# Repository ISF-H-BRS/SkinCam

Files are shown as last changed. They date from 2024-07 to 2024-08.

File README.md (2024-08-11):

# ISF SkinCam

## Introduction

The objective of the SkinCam project was to implement a camera system for real-time skin detection and face verification using multispectral short-wavelength infrared (SWIR) imaging. It originated from previous research projects carried out at Bonn-Rhein-Sieg University of Applied Sciences, such as [FeGeb](https://www.h-brs.de/de/fegeb) and [Beyond SPAI](https://www.h-brs.de/en/beyond-spai).

<p align="center">
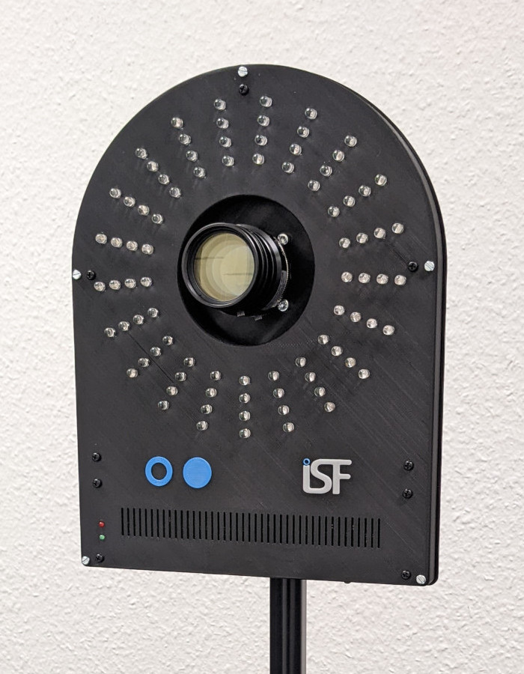
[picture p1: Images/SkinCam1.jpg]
  
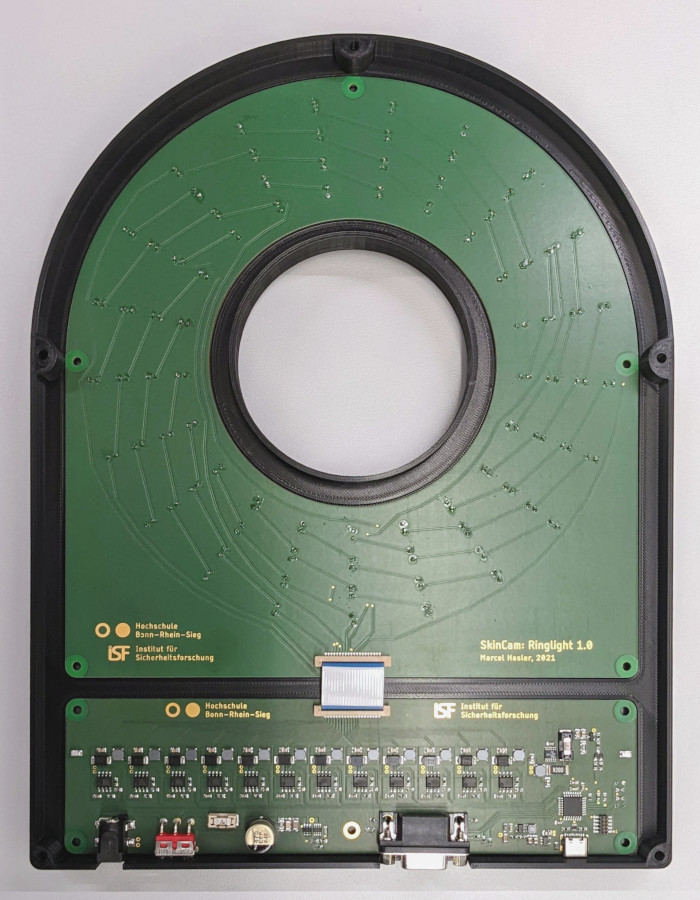
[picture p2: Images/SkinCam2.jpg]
  
</p>

Based on the original concepts and designs, a new and improved system was developed, offering higher frame rates and optimized SWIR lighting. It is currently being used in various successor projects in biometrics research, such as [BIOLAB](https://www.h-brs.de/en/isf/biolab).

<p align="center">
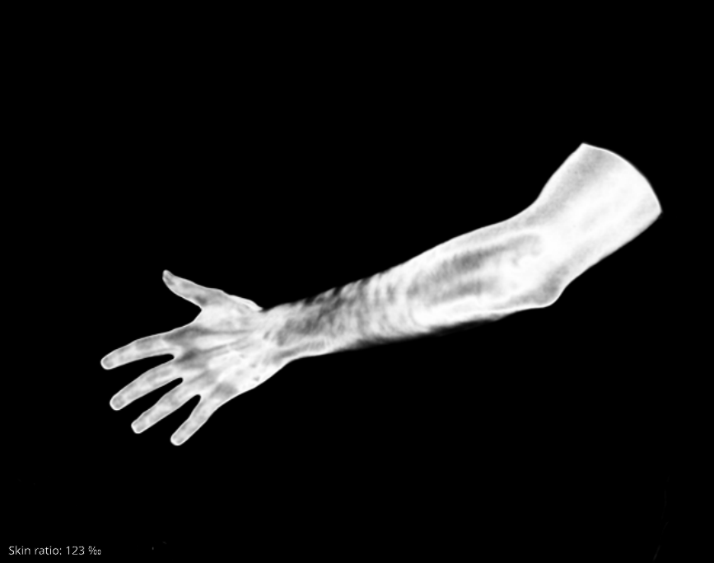
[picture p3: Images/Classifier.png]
  
</p>

## Concept

The system is based on a Goldeye G-033 SWIR camera by Allied Vision, combined with a multispectral ring light operating at wavelengths of 1050, 1300 and 1550 nm. By evaluating the absorption ratios at these specific wavelengths, it is possible to identify those pixels which have properties characteristic of human skin using a pre-trained classifier.

<p align="center">
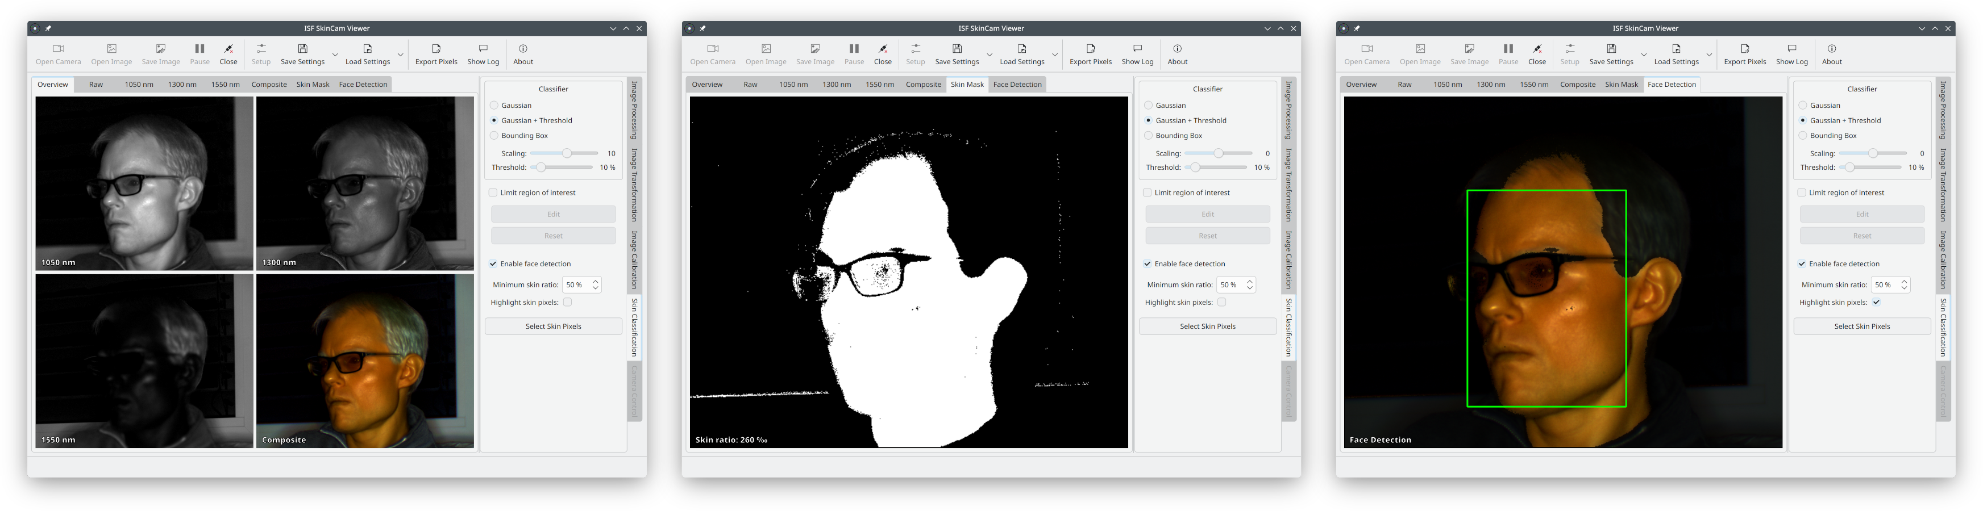
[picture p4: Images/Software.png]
  
</p>

## Software

The software developed as part of this project is based on code originally written for the project Beyond SPAI, which itself was based on the FeGeb project but extended the original concept by using three SWIR cameras simultaneously, using relay optics to split the image.

A number of image processing filters were implemented to compensate for imperfections in the relay optics. While these aren't strictly necessary for a single-camera system, they were retained in the SkinCam software anyway.

The implementation uses OpenCL for real-time image processing and skin classification and employs a number of other optimizations in order to achieve a stable frame rate of 40 Hz even on mid- to low-end systems.

In addition to the OpenCL [development headers](https://github.com/KhronosGroup/OpenCL-CLHPP), [Qt6](https://www.qt.io/product/qt6), [FreeImage](https://freeimage.sourceforge.io/), [libIFD](https://github.com/ISF-H-BRS/FaceDetector), [libusb](https://libusb.info/), [libzip](https://libzip.org/) and the [Vimba SDK](https://www.alliedvision.com/en/products/vimba-sdk/) are required to build and run the software. Since the Vimba terms and conditions do not permit end-users to download or use the software, the SkinCam software is by default compiled without support for the Vimba SDK.

The firmware directory contains project files for both the newly developed system, which is based on a STM32 microcontroller, as well as for the original FeGeb system, which was based on an 8-bit AVR microcontroller.

A number of captured test images are provided within the repository that can be used to evaluate the software without having the actual camera system available. A setup file is also provided, containing suitable settings as well as necessary calibration and classification data.

## License

All source code for the software and firmware is licensed under the terms of the GNU General Public License (GPLv3). All schematics, layout and CAD files are licensed under the terms of the Creative Commons Attribution-ShareAlike International Public License (CC BY-SA). See COPYING in the respective subdirectories for details.

## Further Information

This document will be expanded over time to further detail some of the underlying concepts. For the time being, detailed information on the original project and concepts can be found in Holger Steiner's PhD thesis, available online [here](http://www.grk1564.uni-siegen.de/publicationPDFbyID?ID=825).

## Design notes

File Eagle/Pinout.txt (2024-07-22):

+--------------+--------+--------+-------+
| Signal       | Hirose | Wire   | D-SUB |
+==============+========+========+=======+
| External GND |      1 | Black  |     1 |
+--------------+--------+--------+-------+
| External 12V |      2 | Red    |     5 |
+--------------+--------+--------+-------+
| Trigger TTL  |      4 | Yellow |     7 |
+--------------+--------+--------+-------+
| Feedback TTL |      6 | Blue   |     8 |
+--------------+--------+--------+-------+
| Isolated GND |      7 | Green  |     2 |
+--------------+--------+--------+-------+
| Isolated PWR |     10 | White  |     6 |
+--------------+--------+--------+-------+
| Trigger ISO  |     11 | Purple |     3 |
+--------------+--------+--------+-------+
| Feedback ISO |     12 | Orange |     4 |
+--------------+--------+--------+-------+

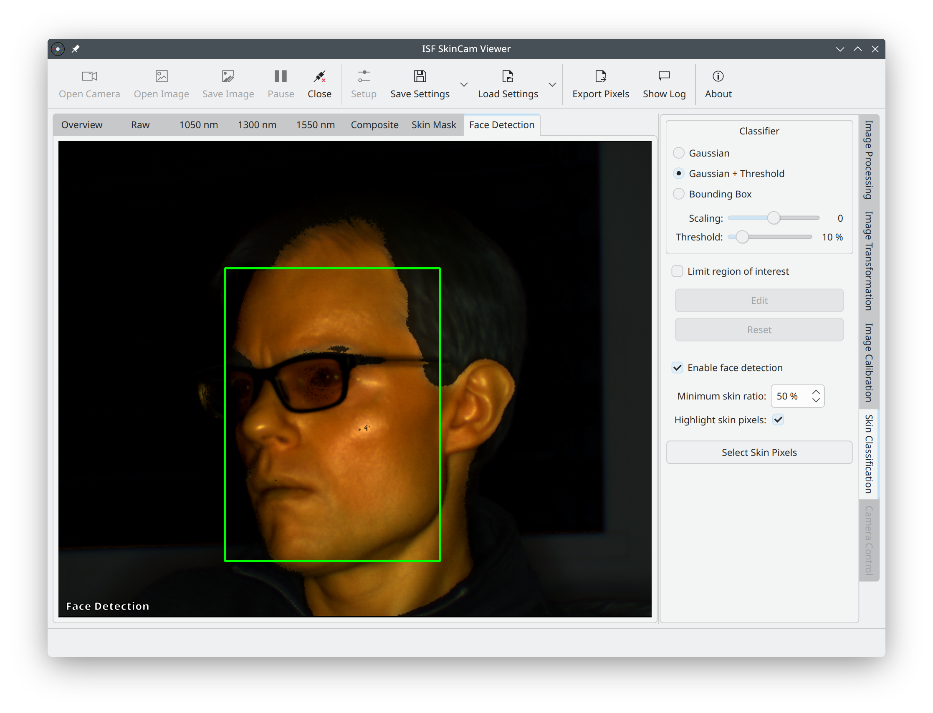
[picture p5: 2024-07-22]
Images/Software3.png

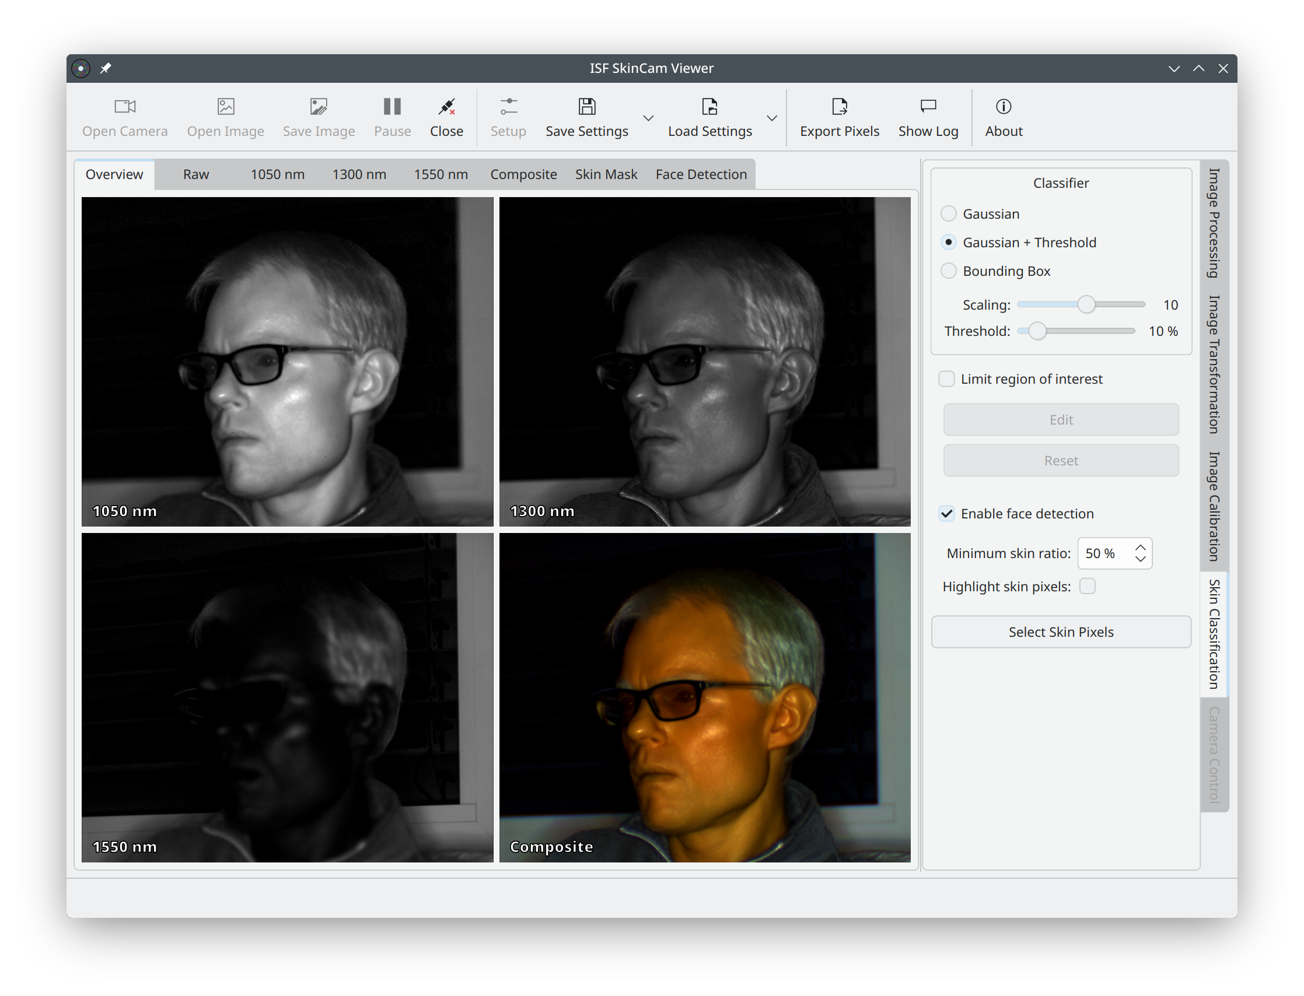
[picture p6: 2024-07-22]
Images/Software1.png

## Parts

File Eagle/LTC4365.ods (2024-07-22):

V_os | 0,003
I_uv | 1E-08
UV_th | 11
OV_th | 13
R1+R2 | 300000
R3 | 6300000
R3 selected | 6340000
R1 | 255384,615384615
R1 selected | 255000
R2 | 45000
R2 selected | 47000
UV_th actual | 10,9966887417219
OV_th actual | 13,0235294117647

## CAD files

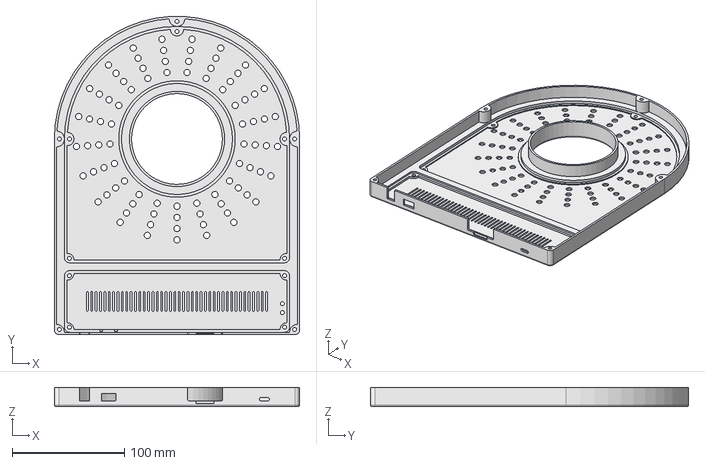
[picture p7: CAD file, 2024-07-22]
FreeCAD/HousingTop.FCStd
219.0 x 283.8 x 17.1 mm

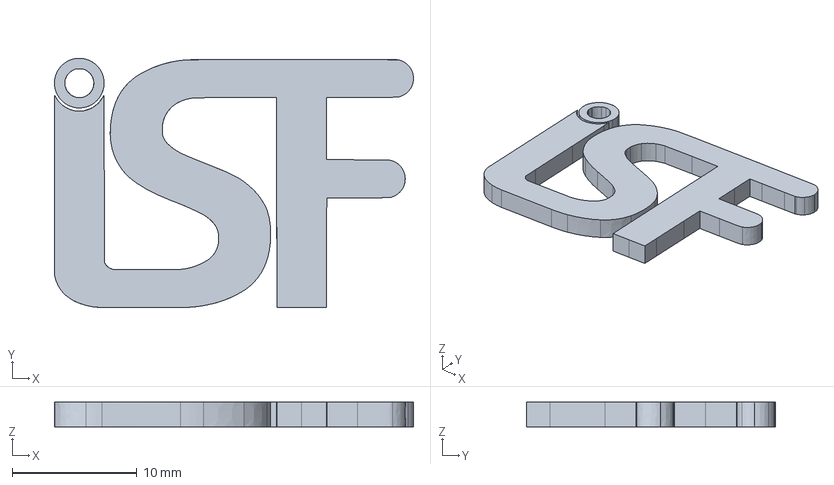
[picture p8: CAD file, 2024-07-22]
FreeCAD/ISF.FCStd
28.8 x 20.0 x 2.00 mm

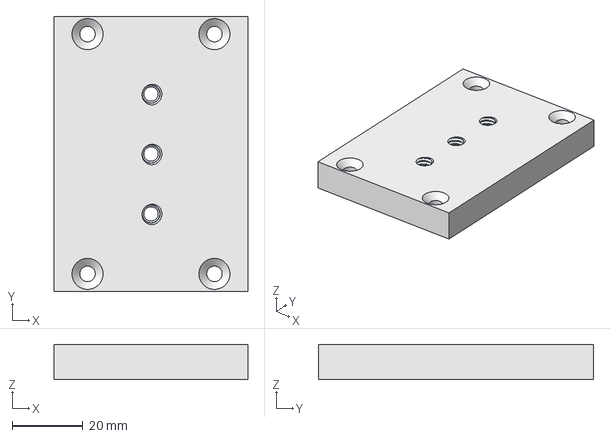
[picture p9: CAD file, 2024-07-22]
FreeCAD/Adapter.FCStd
55.0 x 78.0 x 10.0 mm

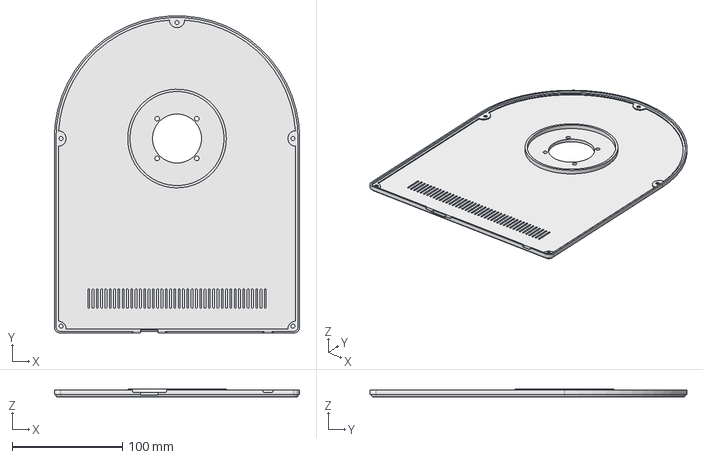
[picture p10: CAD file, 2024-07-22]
FreeCAD/HousingBottom.FCStd
222.4 x 287.2 x 7.00 mm

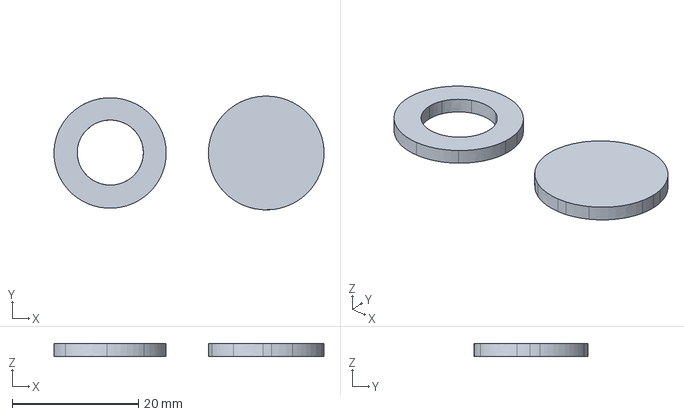
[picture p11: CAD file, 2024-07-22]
FreeCAD/H-BRS.FCStd
42.7 x 18.0 x 2.00 mm

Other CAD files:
FreeCAD/SharedData.FCStd

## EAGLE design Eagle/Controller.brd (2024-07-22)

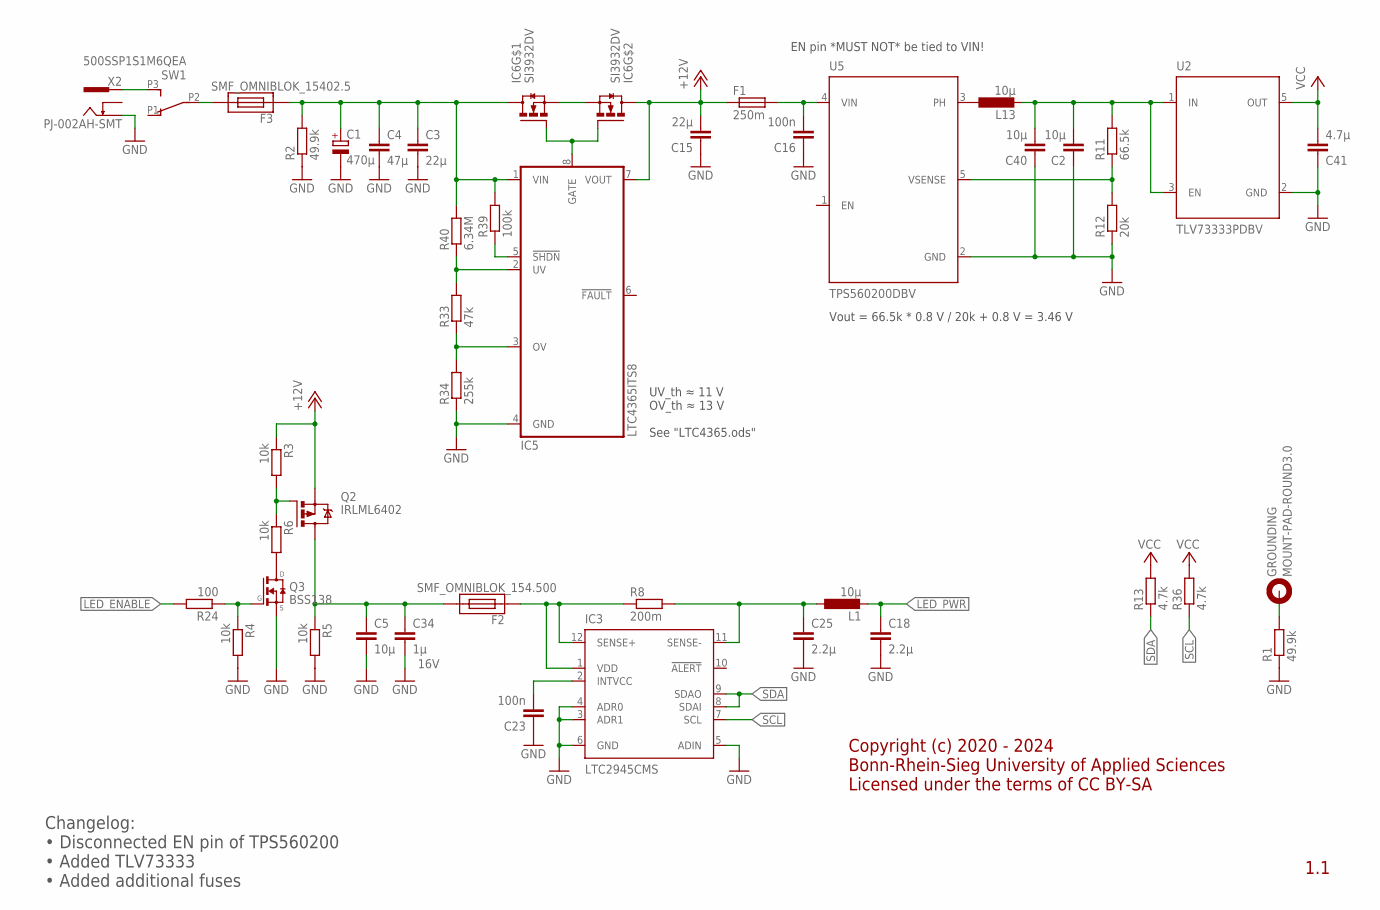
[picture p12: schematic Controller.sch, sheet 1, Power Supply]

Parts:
C1: 470µ; UD-10X10_NICHICON
C2, C5, C40: 10µ; C0805
C3: 22µ; C1206
C4: 47µ; C1206
C15: 22µ; C0805
C16, C23: 100n; C0603
C18, C25: 2.2µ; C0805
C34: 1µ; C0805; RATING 16V
C41: 4.7µ; C0805
F1: 250m; R0603
F2: SMF_OMNIBLOK_154.500; NANO2_SMF_FUSEBLOCK
F3: SMF_OMNIBLOK_15402.5; NANO2_SMF_FUSEBLOCK
GROUNDING: MOUNT-PAD-ROUND3.0; 3,0-PAD
IC3: LTC2945CMS; MSOP12
IC5: LTC4365ITS8; TSOT-23-8
IC6: SI3932DV; TSOT-23-6
L1: 10µ; SMD
L13: 10µ; 2SMD
Q2: IRLML6402; MICRO3
Q3: BSS138; SOT23
R1: 49.9k; R0805
R2: 49.9k; R1206
R3, R4, R6: 10k; R0603
R5: 10k; R1206
R8: 200m; R2512
R11: 66.5k; R0603
R12: 20k; R0603
R13, R36: 4.7k; R0603
R24: 100; R0603
R33: 47k; R0603
R34: 255k; R0603
R39: 100k; R0603
R40: 6.34M; R0603
SW1: 500SSP1S1M6QEA
U2: TLV73333PDBV; SOT-23
U5: TPS560200DBV; SOT-23
X2: PJ-002AH-SMT

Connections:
+12V: C15.2, F1.1, IC5.7 (VOUT), IC6.4 (D), Q2.2 (S), R3.1; also elsewhere on the board
GND: C1.-, C2.1, C3.2, C4.2, C5.2, C15.1, C16.1, C18.2, C23.1, C25.2, C34.2, C40.1, C41.1, IC3.3 (ADR1), IC3.4 (ADR0), IC3.5 (ADIN), IC3.6 (GND), IC5.4 (GND), Q3.2 (S), R1.1, R2.1, R4.2, R5.2, R12.1, R34.1, U2.2 (GND), U5.2 (GND), X2.2 (OUT); also elsewhere on the board
LED_ENABLE: R24.2; also elsewhere on the board
LED_PWR: C18.1, L1.2; also elsewhere on the board
unnamed: GROUNDING.B3,0, R1.2
unnamed: C2.2, C40.2, L13.P$2 (2), R11.2, U2.1 (IN), U2.3 (EN)
unnamed: C25.1, IC3.11 (SENSE-), L1.1, R8.2
unnamed: C16.2, F1.2, U5.4 (VIN)
unnamed: Q2.1 (G), R3.2, R6.1
unnamed: Q3.1 (G), R4.1, R24.1
unnamed: Q3.3 (D), R6.2
unnamed: C5.1, C34.1, F2.2, Q2.3 (D), R5.1
unnamed: SW1.P3 (3), X2.1-1 (IN), X2.1-2 (IN)
unnamed: L13.P$1 (1), U5.3 (PH)
unnamed: C1.+, C3.1, C4.1, F3.1, IC5.1 (VIN), IC6.6 (D), R2.2, R39.2, R40.2
unnamed: R11.1, R12.2, U5.5 (VSENSE)
unnamed: F2.1, IC3.1 (VDD), IC3.12 (SENSE+), R8.1
unnamed: F3.2, SW1.P2 (2)
unnamed: IC5.8 (GATE), IC6.1 (G), IC6.3 (G)
unnamed: IC5.3 (OV), R33.1, R34.2
unnamed: IC5.2 (UV), R33.2, R40.1
unnamed: IC5.5 (!SHDN), R39.1
unnamed: IC6.2 (S), IC6.5 (S)
unnamed: C23.2, IC3.2 (INTVCC)
SCL: IC3.7 (SCL), R36.1; also elsewhere on the board
SDA: IC3.8 (SDAI), IC3.9 (SDAO), R13.1; also elsewhere on the board
VCC: C41.2, R13.2, R36.2, U2.5 (OUT); also elsewhere on the board

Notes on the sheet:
Vout = 66.5k * 0.8 V / 20k + 0.8 V = 3.46 V
UV_th ≈ 11 V OV_th ≈ 13 V See "LTC4365.ods"
1.1
EN pin *MUST NOT* be tied to VIN!
Changelog: • Disconnected EN pin of TPS560200 • Added TLV73333 • Added additional fuses
Copyright (c) 2020 - 2024 Bonn-Rhein-Sieg University of Applied Sciences Licensed under the terms of CC BY-SA

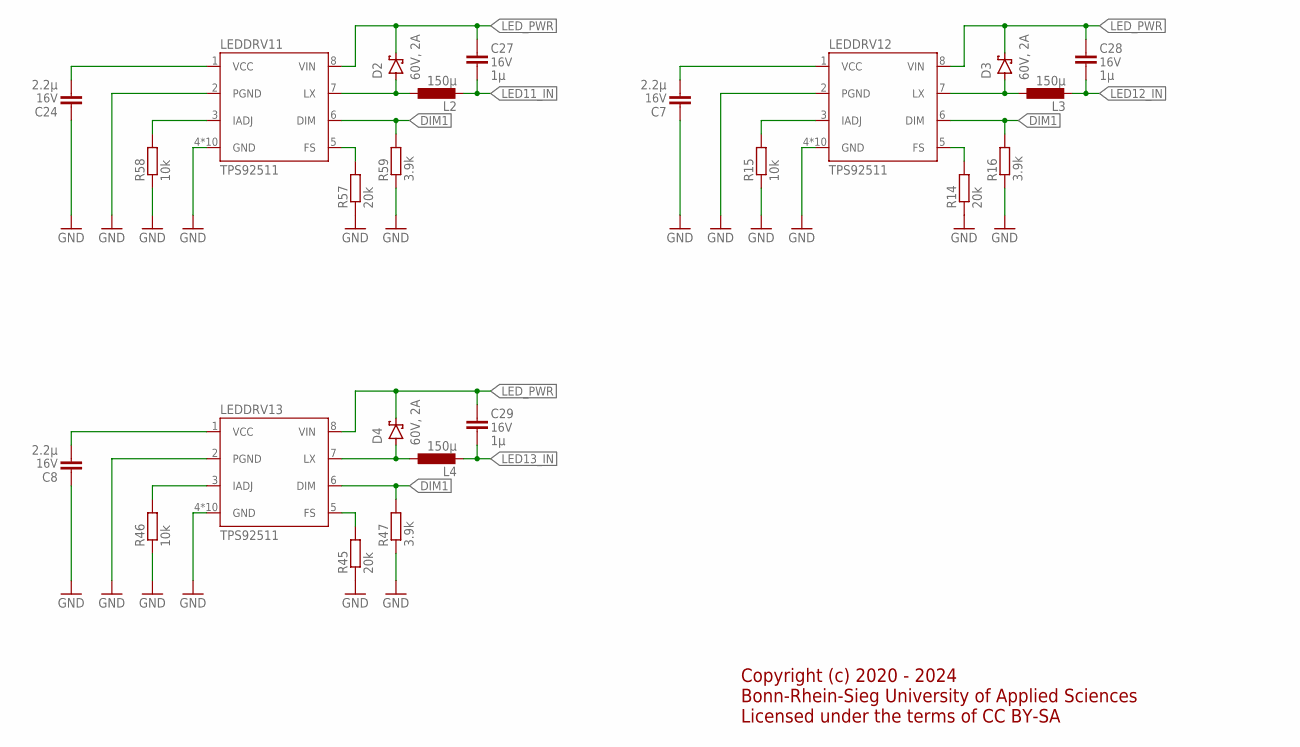
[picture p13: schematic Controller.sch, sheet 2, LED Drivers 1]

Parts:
C7, C8, C24: 2.2µ; C0603; RATING 16V
C27, C28, C29: 1µ; C0805; RATING 16V
D2, D3, D4: 60V, 2A; SMB
L2, L3, L4: 150µ; SMD
LEDDRV11, LEDDRV12, LEDDRV13: TPS92511; SOIC-8-EP
R14, R45, R57: 20k; R0603
R15, R46, R58: 10k; R0603
R16, R47, R59: 3.9k; R0603

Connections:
DIM1: LEDDRV11.6 (DIM), LEDDRV12.6 (DIM), LEDDRV13.6 (DIM), R16.2, R47.2, R59.2; also elsewhere on the board
GND: C7.1, C8.1, C24.1, LEDDRV11.2 (PGND), LEDDRV11.4 (GND), LEDDRV11.EPAD (GND), LEDDRV11.P$1 (GND), LEDDRV11.P$2 (GND), LEDDRV11.P$3 (GND), LEDDRV11.P$4 (GND), LEDDRV11.P$5 (GND), LEDDRV11.P$6 (GND), LEDDRV11.P$7 (GND), LEDDRV11.P$8 (GND), LEDDRV12.2 (PGND), LEDDRV12.4 (GND), LEDDRV12.EPAD (GND), LEDDRV12.P$1 (GND), LEDDRV12.P$2 (GND), LEDDRV12.P$3 (GND), LEDDRV12.P$4 (GND), LEDDRV12.P$5 (GND), LEDDRV12.P$6 (GND), LEDDRV12.P$7 (GND), LEDDRV12.P$8 (GND), LEDDRV13.2 (PGND), LEDDRV13.4 (GND), LEDDRV13.EPAD (GND), LEDDRV13.P$1 (GND), LEDDRV13.P$2 (GND), LEDDRV13.P$3 (GND), LEDDRV13.P$4 (GND), LEDDRV13.P$5 (GND), LEDDRV13.P$6 (GND), LEDDRV13.P$7 (GND), LEDDRV13.P$8 (GND), R14.1, R15.1, R16.1, R45.1, R46.1, R47.1, R57.1, R58.1, R59.1; also elsewhere on the board
LED11_IN: C27.2, L2.2; also elsewhere on the board
LED12_IN: C28.2, L3.2; also elsewhere on the board
LED13_IN: C29.2, L4.2; also elsewhere on the board
LED_PWR: C27.1, C28.1, C29.1, D2.C, D3.C, D4.C, LEDDRV11.8 (VIN), LEDDRV12.8 (VIN), LEDDRV13.8 (VIN); also elsewhere on the board
unnamed: D3.A, L3.1, LEDDRV12.7 (LX)
unnamed: LEDDRV12.5 (FS), R14.2
unnamed: LEDDRV12.3 (IADJ), R15.2
unnamed: C7.2, LEDDRV12.1 (VCC)
unnamed: D4.A, L4.1, LEDDRV13.7 (LX)
unnamed: LEDDRV13.5 (FS), R45.2
unnamed: LEDDRV13.3 (IADJ), R46.2
unnamed: C8.2, LEDDRV13.1 (VCC)
unnamed: D2.A, L2.1, LEDDRV11.7 (LX)
unnamed: LEDDRV11.5 (FS), R57.2
unnamed: LEDDRV11.3 (IADJ), R58.2
unnamed: C24.2, LEDDRV11.1 (VCC)

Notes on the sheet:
Copyright (c) 2020 - 2024 Bonn-Rhein-Sieg University of Applied Sciences Licensed under the terms of CC BY-SA

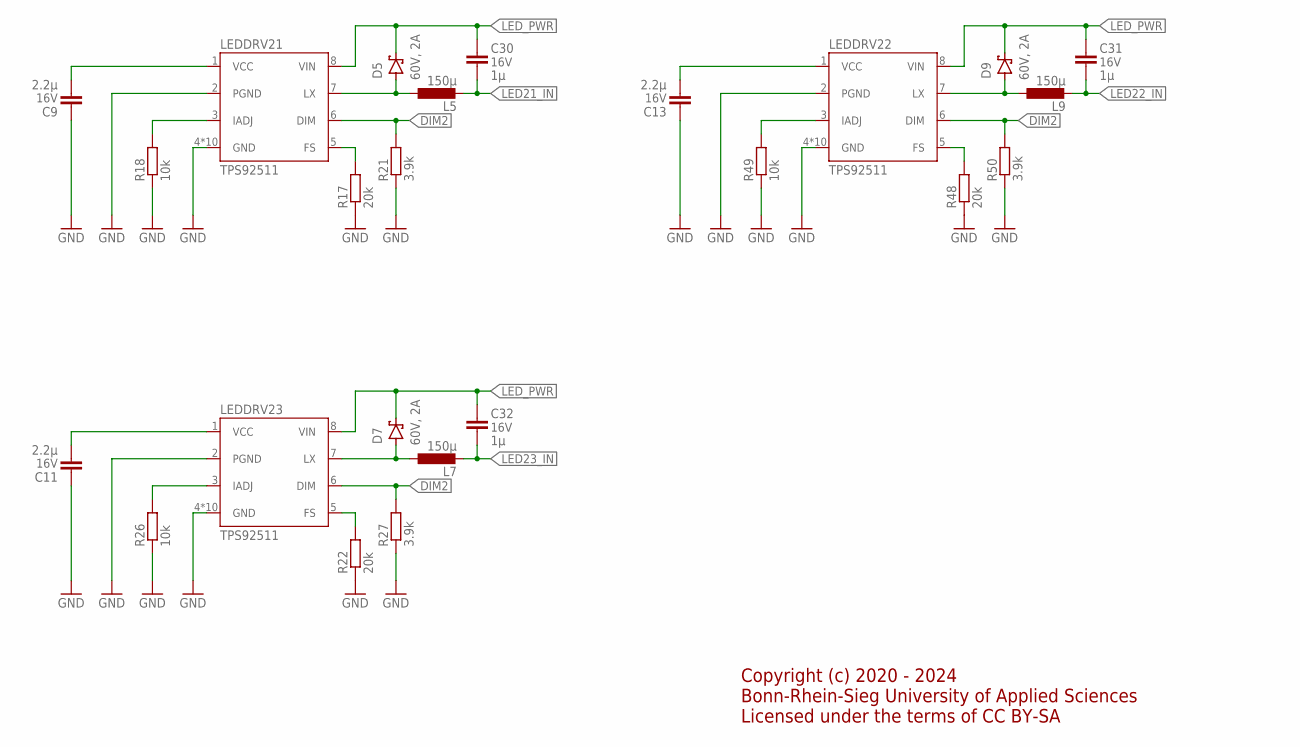
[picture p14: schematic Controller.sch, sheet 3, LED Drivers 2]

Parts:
C9, C11, C13: 2.2µ; C0603; RATING 16V
C30, C31, C32: 1µ; C0805; RATING 16V
D5, D7, D9: 60V, 2A; SMB
L5, L7, L9: 150µ; SMD
LEDDRV21, LEDDRV22, LEDDRV23: TPS92511; SOIC-8-EP
R17, R22, R48: 20k; R0603
R18, R26, R49: 10k; R0603
R21, R27, R50: 3.9k; R0603

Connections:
DIM2: LEDDRV21.6 (DIM), LEDDRV22.6 (DIM), LEDDRV23.6 (DIM), R21.2, R27.2, R50.2; also elsewhere on the board
GND: C9.1, C11.1, C13.1, LEDDRV21.2 (PGND), LEDDRV21.4 (GND), LEDDRV21.EPAD (GND), LEDDRV21.P$1 (GND), LEDDRV21.P$2 (GND), LEDDRV21.P$3 (GND), LEDDRV21.P$4 (GND), LEDDRV21.P$5 (GND), LEDDRV21.P$6 (GND), LEDDRV21.P$7 (GND), LEDDRV21.P$8 (GND), LEDDRV22.2 (PGND), LEDDRV22.4 (GND), LEDDRV22.EPAD (GND), LEDDRV22.P$1 (GND), LEDDRV22.P$2 (GND), LEDDRV22.P$3 (GND), LEDDRV22.P$4 (GND), LEDDRV22.P$5 (GND), LEDDRV22.P$6 (GND), LEDDRV22.P$7 (GND), LEDDRV22.P$8 (GND), LEDDRV23.2 (PGND), LEDDRV23.4 (GND), LEDDRV23.EPAD (GND), LEDDRV23.P$1 (GND), LEDDRV23.P$2 (GND), LEDDRV23.P$3 (GND), LEDDRV23.P$4 (GND), LEDDRV23.P$5 (GND), LEDDRV23.P$6 (GND), LEDDRV23.P$7 (GND), LEDDRV23.P$8 (GND), R17.1, R18.1, R21.1, R22.1, R26.1, R27.1, R48.1, R49.1, R50.1; also elsewhere on the board
LED21_IN: C30.2, L5.2; also elsewhere on the board
LED22_IN: C31.2, L9.2; also elsewhere on the board
LED23_IN: C32.2, L7.2; also elsewhere on the board
LED_PWR: C30.1, C31.1, C32.1, D5.C, D7.C, D9.C, LEDDRV21.8 (VIN), LEDDRV22.8 (VIN), LEDDRV23.8 (VIN); also elsewhere on the board
unnamed: D5.A, L5.1, LEDDRV21.7 (LX)
unnamed: LEDDRV21.5 (FS), R17.2
unnamed: LEDDRV21.3 (IADJ), R18.2
unnamed: C9.2, LEDDRV21.1 (VCC)
unnamed: D7.A, L7.1, LEDDRV23.7 (LX)
unnamed: LEDDRV23.5 (FS), R22.2
unnamed: LEDDRV23.3 (IADJ), R26.2
unnamed: C11.2, LEDDRV23.1 (VCC)
unnamed: D9.A, L9.1, LEDDRV22.7 (LX)
unnamed: LEDDRV22.5 (FS), R48.2
unnamed: LEDDRV22.3 (IADJ), R49.2
unnamed: C13.2, LEDDRV22.1 (VCC)

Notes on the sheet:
Copyright (c) 2020 - 2024 Bonn-Rhein-Sieg University of Applied Sciences Licensed under the terms of CC BY-SA

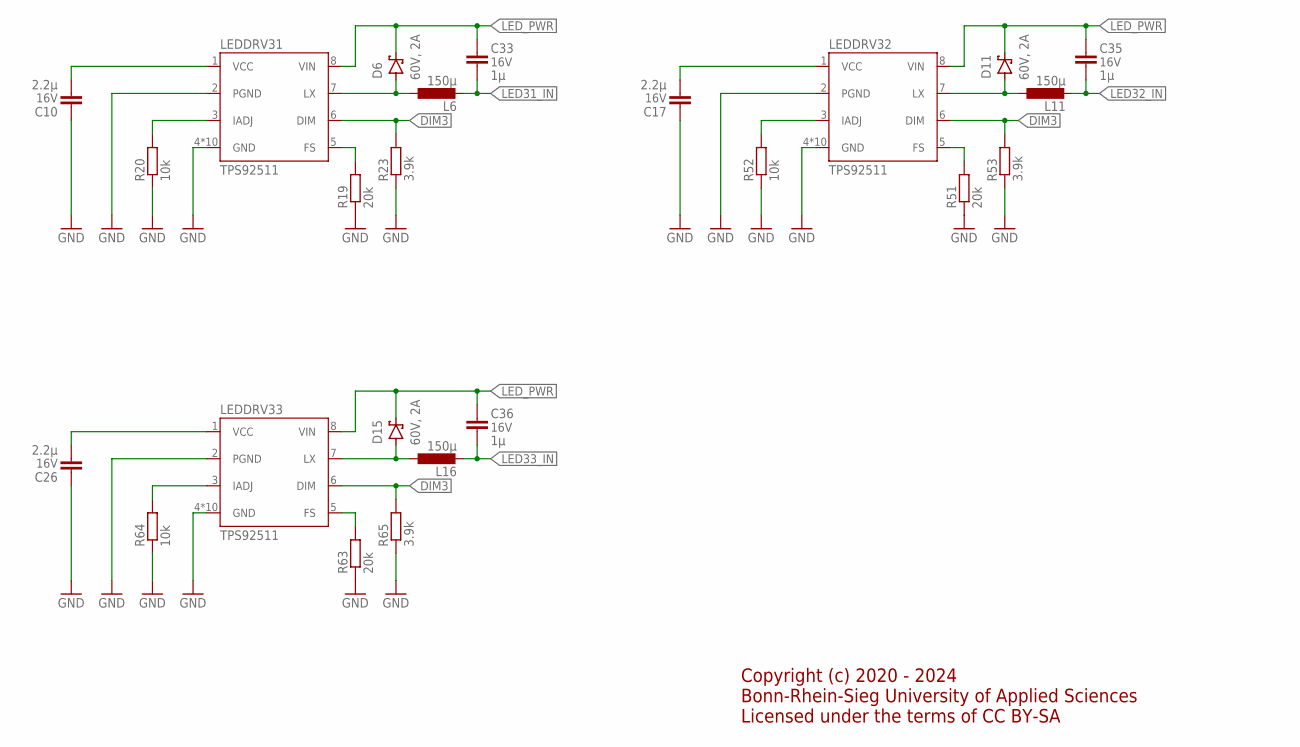
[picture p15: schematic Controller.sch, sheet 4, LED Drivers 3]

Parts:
C10, C17, C26: 2.2µ; C0603; RATING 16V
C33, C35, C36: 1µ; C0805; RATING 16V
D6, D11, D15: 60V, 2A; SMB
L6, L11, L16: 150µ; SMD
LEDDRV31, LEDDRV32, LEDDRV33: TPS92511; SOIC-8-EP
R19, R51, R63: 20k; R0603
R20, R52, R64: 10k; R0603
R23, R53, R65: 3.9k; R0603

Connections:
DIM3: LEDDRV31.6 (DIM), LEDDRV32.6 (DIM), LEDDRV33.6 (DIM), R23.2, R53.2, R65.2; also elsewhere on the board
GND: C10.1, C17.1, C26.1, LEDDRV31.2 (PGND), LEDDRV31.4 (GND), LEDDRV31.EPAD (GND), LEDDRV31.P$1 (GND), LEDDRV31.P$2 (GND), LEDDRV31.P$3 (GND), LEDDRV31.P$4 (GND), LEDDRV31.P$5 (GND), LEDDRV31.P$6 (GND), LEDDRV31.P$7 (GND), LEDDRV31.P$8 (GND), LEDDRV32.2 (PGND), LEDDRV32.4 (GND), LEDDRV32.EPAD (GND), LEDDRV32.P$1 (GND), LEDDRV32.P$2 (GND), LEDDRV32.P$3 (GND), LEDDRV32.P$4 (GND), LEDDRV32.P$5 (GND), LEDDRV32.P$6 (GND), LEDDRV32.P$7 (GND), LEDDRV32.P$8 (GND), LEDDRV33.2 (PGND), LEDDRV33.4 (GND), LEDDRV33.EPAD (GND), LEDDRV33.P$1 (GND), LEDDRV33.P$2 (GND), LEDDRV33.P$3 (GND), LEDDRV33.P$4 (GND), LEDDRV33.P$5 (GND), LEDDRV33.P$6 (GND), LEDDRV33.P$7 (GND), LEDDRV33.P$8 (GND), R19.1, R20.1, R23.1, R51.1, R52.1, R53.1, R63.1, R64.1, R65.1; also elsewhere on the board
LED31_IN: C33.2, L6.2; also elsewhere on the board
LED32_IN: C35.2, L11.2; also elsewhere on the board
LED33_IN: C36.2, L16.2; also elsewhere on the board
LED_PWR: C33.1, C35.1, C36.1, D6.C, D11.C, D15.C, LEDDRV31.8 (VIN), LEDDRV32.8 (VIN), LEDDRV33.8 (VIN); also elsewhere on the board
unnamed: D6.A, L6.1, LEDDRV31.7 (LX)
unnamed: LEDDRV31.5 (FS), R19.2
unnamed: LEDDRV31.3 (IADJ), R20.2
unnamed: C10.2, LEDDRV31.1 (VCC)
unnamed: D11.A, L11.1, LEDDRV32.7 (LX)
unnamed: LEDDRV32.5 (FS), R51.2
unnamed: LEDDRV32.3 (IADJ), R52.2
unnamed: C17.2, LEDDRV32.1 (VCC)
unnamed: D15.A, L16.1, LEDDRV33.7 (LX)
unnamed: LEDDRV33.5 (FS), R63.2
unnamed: LEDDRV33.3 (IADJ), R64.2
unnamed: C26.2, LEDDRV33.1 (VCC)

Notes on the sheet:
Copyright (c) 2020 - 2024 Bonn-Rhein-Sieg University of Applied Sciences Licensed under the terms of CC BY-SA

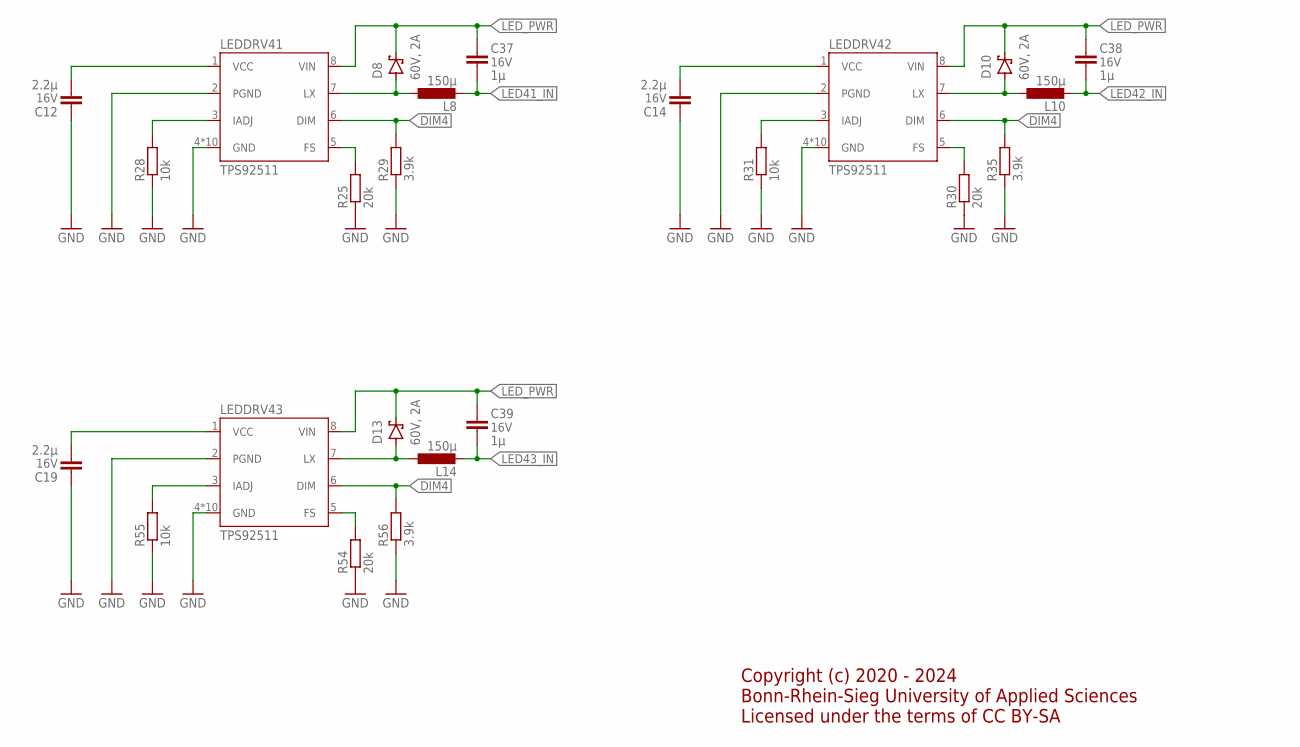
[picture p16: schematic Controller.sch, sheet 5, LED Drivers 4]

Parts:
C12, C14, C19: 2.2µ; C0603; RATING 16V
C37, C38, C39: 1µ; C0805; RATING 16V
D8, D10, D13: 60V, 2A; SMB
L8, L10, L14: 150µ; SMD
LEDDRV41, LEDDRV42, LEDDRV43: TPS92511; SOIC-8-EP
R25, R30, R54: 20k; R0603
R28, R31, R55: 10k; R0603
R29, R35, R56: 3.9k; R0603

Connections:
DIM4: LEDDRV41.6 (DIM), LEDDRV42.6 (DIM), LEDDRV43.6 (DIM), R29.2, R35.2, R56.2; also elsewhere on the board
GND: C12.1, C14.1, C19.1, LEDDRV41.2 (PGND), LEDDRV41.4 (GND), LEDDRV41.EPAD (GND), LEDDRV41.P$1 (GND), LEDDRV41.P$2 (GND), LEDDRV41.P$3 (GND), LEDDRV41.P$4 (GND), LEDDRV41.P$5 (GND), LEDDRV41.P$6 (GND), LEDDRV41.P$7 (GND), LEDDRV41.P$8 (GND), LEDDRV42.2 (PGND), LEDDRV42.4 (GND), LEDDRV42.EPAD (GND), LEDDRV42.P$1 (GND), LEDDRV42.P$2 (GND), LEDDRV42.P$3 (GND), LEDDRV42.P$4 (GND), LEDDRV42.P$5 (GND), LEDDRV42.P$6 (GND), LEDDRV42.P$7 (GND), LEDDRV42.P$8 (GND), LEDDRV43.2 (PGND), LEDDRV43.4 (GND), LEDDRV43.EPAD (GND), LEDDRV43.P$1 (GND), LEDDRV43.P$2 (GND), LEDDRV43.P$3 (GND), LEDDRV43.P$4 (GND), LEDDRV43.P$5 (GND), LEDDRV43.P$6 (GND), LEDDRV43.P$7 (GND), LEDDRV43.P$8 (GND), R25.1, R28.1, R29.1, R30.1, R31.1, R35.1, R54.1, R55.1, R56.1; also elsewhere on the board
LED41_IN: C37.2, L8.2; also elsewhere on the board
LED42_IN: C38.2, L10.2; also elsewhere on the board
LED43_IN: C39.2, L14.2; also elsewhere on the board
LED_PWR: C37.1, C38.1, C39.1, D8.C, D10.C, D13.C, LEDDRV41.8 (VIN), LEDDRV42.8 (VIN), LEDDRV43.8 (VIN); also elsewhere on the board
unnamed: D8.A, L8.1, LEDDRV41.7 (LX)
unnamed: LEDDRV41.5 (FS), R25.2
unnamed: LEDDRV41.3 (IADJ), R28.2
unnamed: C12.2, LEDDRV41.1 (VCC)
unnamed: D10.A, L10.1, LEDDRV42.7 (LX)
unnamed: LEDDRV42.5 (FS), R30.2
unnamed: LEDDRV42.3 (IADJ), R31.2
unnamed: C14.2, LEDDRV42.1 (VCC)
unnamed: D13.A, L14.1, LEDDRV43.7 (LX)
unnamed: LEDDRV43.5 (FS), R54.2
unnamed: LEDDRV43.3 (IADJ), R55.2
unnamed: C19.2, LEDDRV43.1 (VCC)

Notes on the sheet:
Copyright (c) 2020 - 2024 Bonn-Rhein-Sieg University of Applied Sciences Licensed under the terms of CC BY-SA

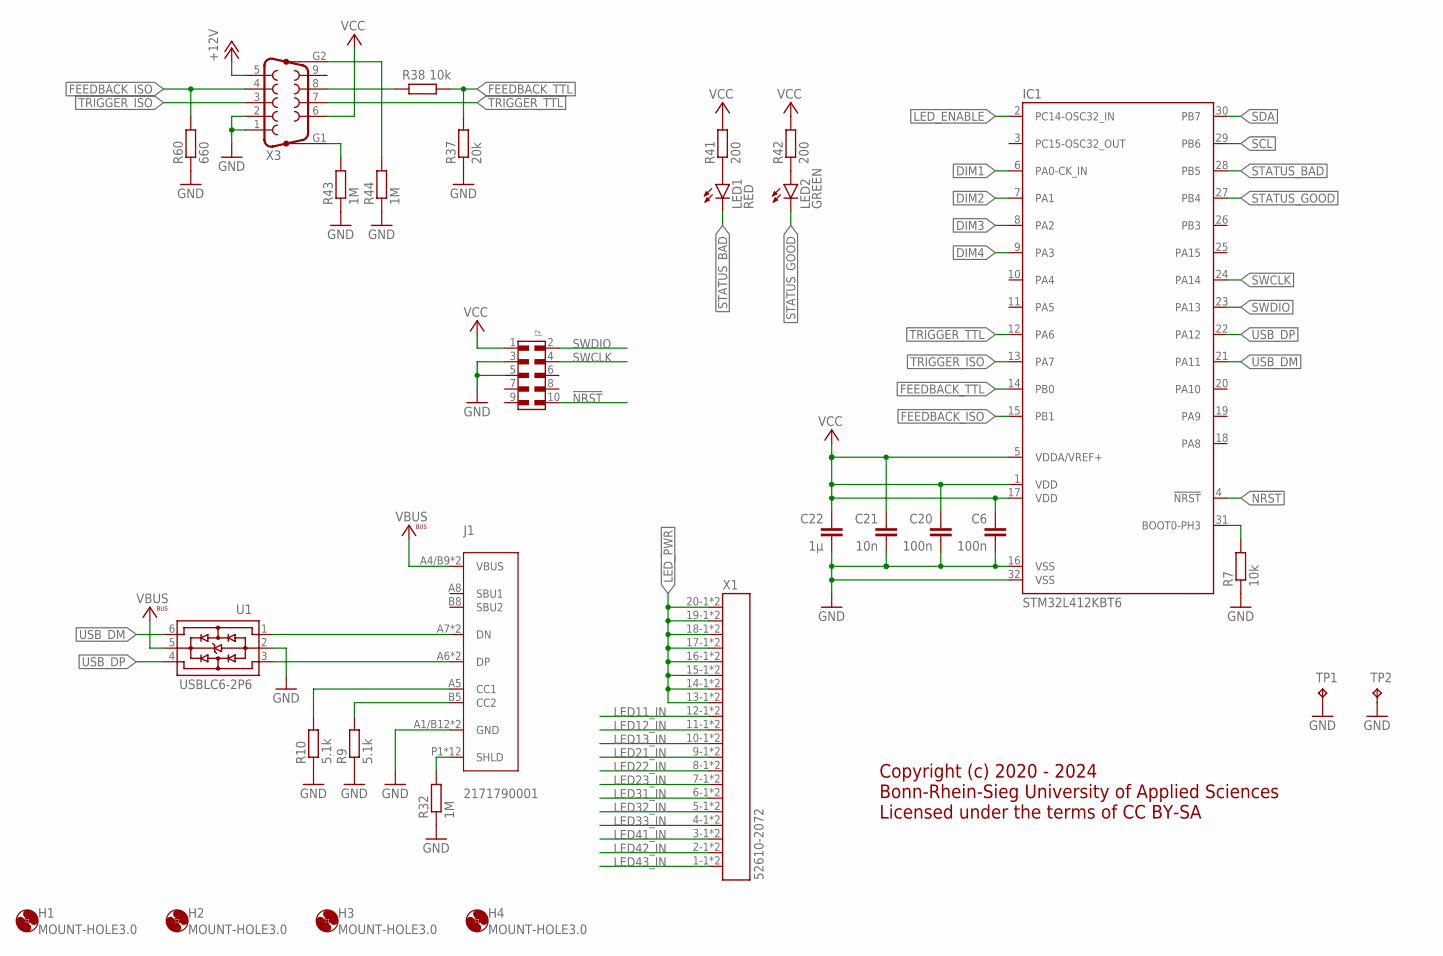
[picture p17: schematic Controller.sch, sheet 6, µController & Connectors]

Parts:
C6, C20: 100n; C0603
C21: 10n; C0603
C22: 1µ; C0603
H1, H2, H3, H4: MOUNT-HOLE3.0; 3,0
IC1: STM32L412KBT6; LQFP32
J1: 2171790001; 2171790001_MOL
J2: 6210XX21021_62101021021; 62101021021
LED1: RED; LED3MM
LED2: GREEN; LED3MM
R7, R38: 10k; R0603
R9, R10: 5.1k; R0603
R32, R43, R44: 1M; R0603
R37: 20k; R0603
R41, R42: 200; R0603
R60: 660; R0603
TP1, TP2: TP3.8X2.03; 3.8X2.03
U1: USBLC6-2P6; SOT-666
X1: 52610-2072
X3: F09HP

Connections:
!NRST: IC1.4 (!NRST), J2.10
+12V: X3.5; also elsewhere on the board
DIM1: IC1.6 (PA0-CK_IN); also elsewhere on the board
DIM2: IC1.7 (PA1); also elsewhere on the board
DIM3: IC1.8 (PA2); also elsewhere on the board
DIM4: IC1.9 (PA3); also elsewhere on the board
FEEDBACK_ISO: IC1.15 (PB1), R60.2, X3.4
FEEDBACK_TTL: IC1.14 (PB0), R37.2, R38.1
GND: C6.2, C20.2, C21.2, C22.2, IC1.16 (VSS), IC1.32 (VSS), J1.A1/B12 (GND), J1.B1/A12 (GND), J2.3, J2.5, R7.1, R9.1, R10.1, R32.1, R37.1, R43.1, R44.1, R60.1, TP1.TP, TP2.TP, U1.2, X3.1, X3.2; also elsewhere on the board
LED11_IN: X1.12-1 (12), X1.12-2 (12); also elsewhere on the board
LED12_IN: X1.11-1 (11), X1.11-2 (11); also elsewhere on the board
LED13_IN: X1.10-1 (10), X1.10-2 (10); also elsewhere on the board
LED21_IN: X1.9-1 (9), X1.9-2 (9); also elsewhere on the board
LED22_IN: X1.8-1 (8), X1.8-2 (8); also elsewhere on the board
LED23_IN: X1.7-1 (7), X1.7-2 (7); also elsewhere on the board
LED31_IN: X1.6-1 (6), X1.6-2 (6); also elsewhere on the board
LED32_IN: X1.5-1 (5), X1.5-2 (5); also elsewhere on the board
LED33_IN: X1.4-1 (4), X1.4-2 (4); also elsewhere on the board
LED41_IN: X1.3-1 (3), X1.3-2 (3); also elsewhere on the board
LED42_IN: X1.2-1 (2), X1.2-2 (2); also elsewhere on the board
LED43_IN: X1.1-1 (1), X1.1-2 (1); also elsewhere on the board
LED_ENABLE: IC1.2 (PC14-OSC32_IN); also elsewhere on the board
LED_PWR: X1.13-1 (13), X1.13-2 (13), X1.14-1 (14), X1.14-2 (14), X1.15-1 (15), X1.15-2 (15), X1.16-1 (16), X1.16-2 (16), X1.17-1 (17), X1.17-2 (17), X1.18-1 (18), X1.18-2 (18), X1.19-1 (19), X1.19-2 (19), X1.20-1 (20), X1.20-2 (20); also elsewhere on the board
unnamed: IC1.31 (BOOT0-PH3), R7.2
unnamed: R43.2, X3.G1
unnamed: J1.A7 (DN), J1.B7 (DN), U1.1
unnamed: J1.A6 (DP), J1.B6 (DP), U1.3
unnamed: J1.B5 (CC2), R9.2
unnamed: J1.A5 (CC1), R10.2
unnamed: J1.P1 (SHLD), J1.P2 (SHLD), J1.P3 (SHLD), J1.P4 (SHLD), J1.S1 (SHLD), J1.S2 (SHLD), J1.S3 (SHLD), J1.S4 (SHLD), J1.S5 (SHLD), J1.S6 (SHLD), J1.S7 (SHLD), J1.S8 (SHLD), R32.2
unnamed: R38.2, X3.8
unnamed: LED1.A, R41.1
unnamed: LED2.A, R42.1
unnamed: R44.2, X3.G2
SCL: IC1.29 (PB6); also elsewhere on the board
SDA: IC1.30 (PB7); also elsewhere on the board
STATUS_BAD: IC1.28 (PB5), LED1.K (C)
STATUS_GOOD: IC1.27 (PB4), LED2.K (C)
SWCLK: IC1.24 (PA14), J2.4
SWDIO: IC1.23 (PA13), J2.2
TRIGGER_ISO: IC1.13 (PA7), X3.3
TRIGGER_TTL: IC1.12 (PA6), X3.7
USB_DM: IC1.21 (PA11), U1.6
USB_DP: IC1.22 (PA12), U1.4
VBUS: J1.A4/B9 (VBUS), J1.B4/A9 (VBUS), U1.5
VCC: C6.1, C20.1, C21.1, C22.1, IC1.1 (VDD), IC1.5 (VDDA/VREF+), IC1.17 (VDD), J2.1, R41.2, R42.2, X3.6; also elsewhere on the board

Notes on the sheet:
Copyright (c) 2020 - 2024 Bonn-Rhein-Sieg University of Applied Sciences Licensed under the terms of CC BY-SA

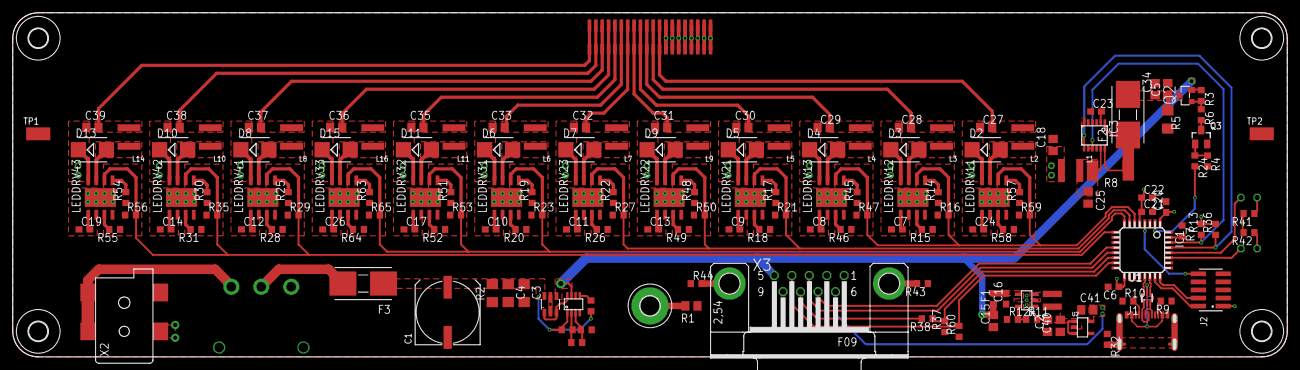
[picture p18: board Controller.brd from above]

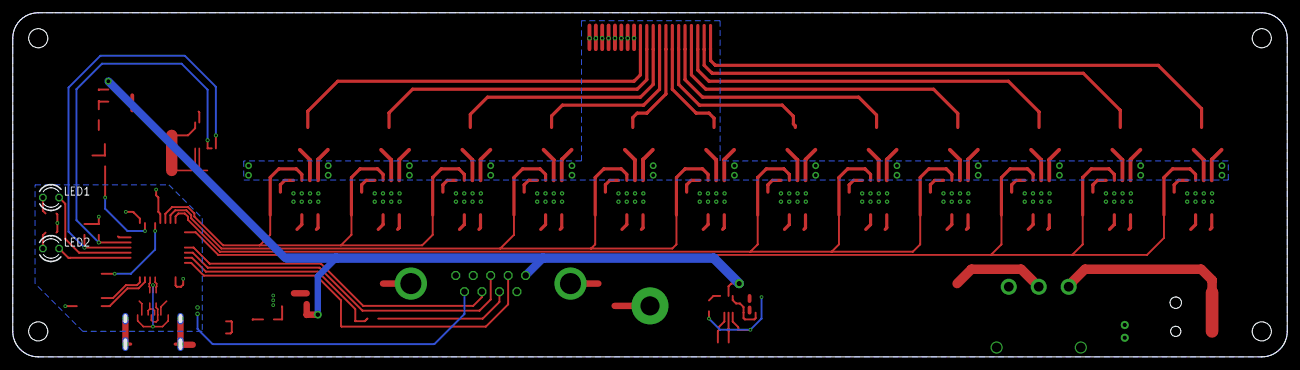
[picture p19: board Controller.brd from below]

Board: 2 copper layers, 200.0 x 54.0 mm, 169 parts (2 on the bottom side), 114 nets.

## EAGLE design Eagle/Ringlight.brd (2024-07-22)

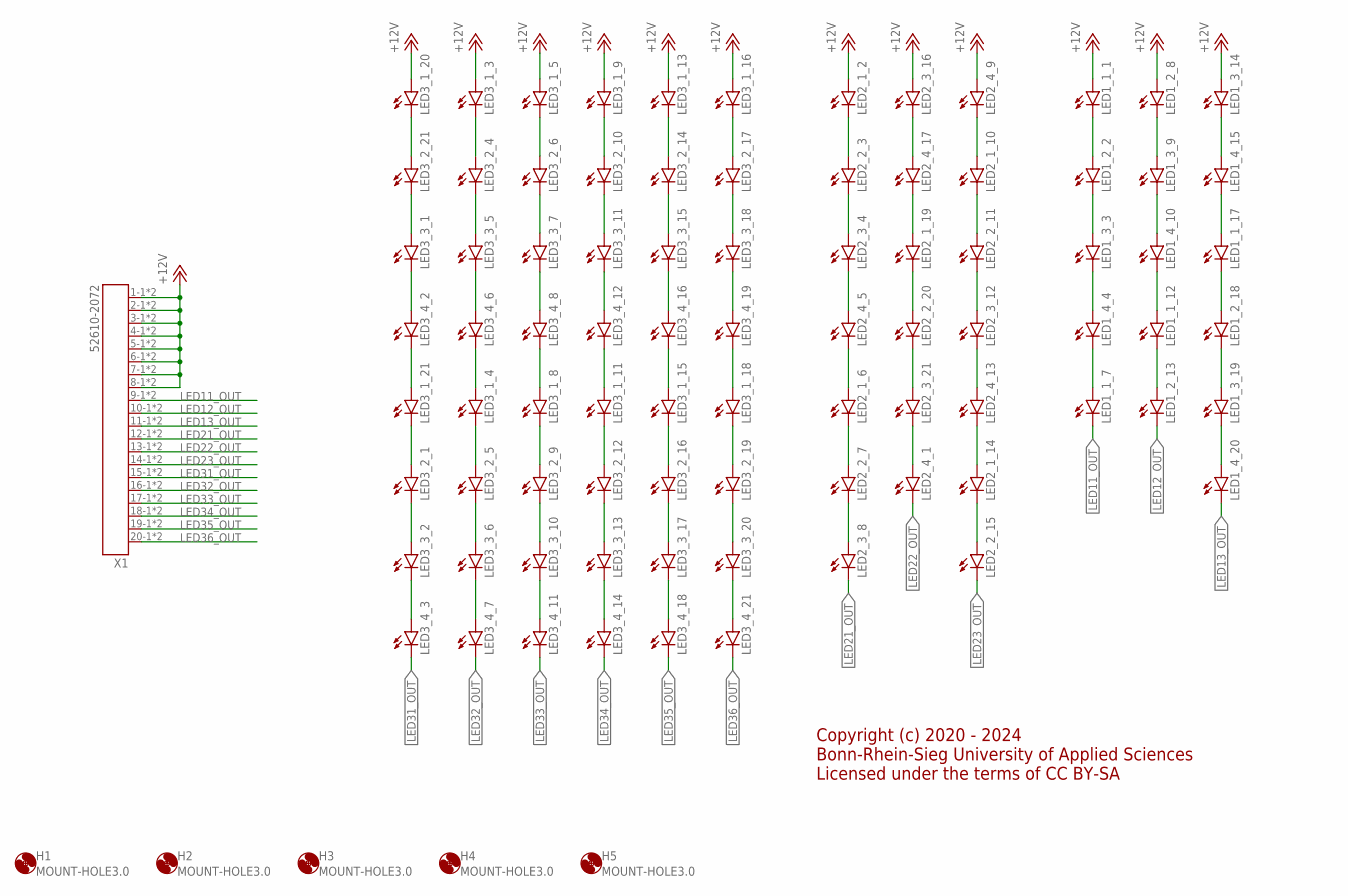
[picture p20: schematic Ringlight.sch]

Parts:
H1, H2, H3, H4, H5: MOUNT-HOLE3.0; 3,0
LED1_1_1, LED1_1_7, LED1_1_12, LED1_1_17, LED1_2_2, LED1_2_8, LED1_2_13, LED1_2_18, LED1_3_3, LED1_3_9, LED1_3_14, LED1_3_19, LED1_4_4, LED1_4_10, LED1_4_15, LED1_4_20, LED2_1_2, LED2_1_6, LED2_1_10, LED2_1_14, LED2_1_19, LED2_2_3, LED2_2_7, LED2_2_11, LED2_2_15, LED2_2_20, LED2_3_4, LED2_3_8, LED2_3_12, LED2_3_16, LED2_3_21, LED2_4_1, LED2_4_5, LED2_4_9, LED2_4_13, LED2_4_17, LED3_1_3, LED3_1_4, LED3_1_5, LED3_1_8, LED3_1_9, LED3_1_11, LED3_1_13, LED3_1_15, LED3_1_16, LED3_1_18, LED3_1_20, LED3_1_21, LED3_2_1, LED3_2_4, LED3_2_5, LED3_2_6, LED3_2_9, LED3_2_10, LED3_2_12, LED3_2_14, LED3_2_16, LED3_2_17, LED3_2_19, LED3_2_21, LED3_3_1, LED3_3_2, LED3_3_5, LED3_3_6, LED3_3_7, LED3_3_10, LED3_3_11, LED3_3_13, LED3_3_15, LED3_3_17, LED3_3_18, LED3_3_20, LED3_4_2, LED3_4_3, LED3_4_6, LED3_4_7, LED3_4_8, LED3_4_11, LED3_4_12, LED3_4_14, LED3_4_16, LED3_4_18, LED3_4_19, LED3_4_21: LED5MM
X1: 52610-2072

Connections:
+12V: LED1_1_1.A, LED1_2_8.A, LED1_3_14.A, LED2_1_2.A, LED2_3_16.A, LED2_4_9.A, LED3_1_3.A, LED3_1_5.A, LED3_1_9.A, LED3_1_13.A, LED3_1_16.A, LED3_1_20.A, X1.1-1 (1), X1.1-2 (1), X1.2-1 (2), X1.2-2 (2), X1.3-1 (3), X1.3-2 (3), X1.4-1 (4), X1.4-2 (4), X1.5-1 (5), X1.5-2 (5), X1.6-1 (6), X1.6-2 (6), X1.7-1 (7), X1.7-2 (7), X1.8-1 (8), X1.8-2 (8)
LED11_OUT: LED1_1_7.K (C), X1.9-1 (9), X1.9-2 (9)
LED12_OUT: LED1_2_13.K (C), X1.10-1 (10), X1.10-2 (10)
LED13_OUT: LED1_4_20.K (C), X1.11-1 (11), X1.11-2 (11)
LED21_OUT: LED2_3_8.K (C), X1.12-1 (12), X1.12-2 (12)
LED22_OUT: LED2_4_1.K (C), X1.13-1 (13), X1.13-2 (13)
LED23_OUT: LED2_2_15.K (C), X1.14-1 (14), X1.14-2 (14)
LED31_OUT: LED3_4_3.K (C), X1.15-1 (15), X1.15-2 (15)
LED32_OUT: LED3_4_7.K (C), X1.16-1 (16), X1.16-2 (16)
LED33_OUT: LED3_4_11.K (C), X1.17-1 (17), X1.17-2 (17)
LED34_OUT: LED3_4_14.K (C), X1.18-1 (18), X1.18-2 (18)
LED35_OUT: LED3_4_18.K (C), X1.19-1 (19), X1.19-2 (19)
LED36_OUT: LED3_4_21.K (C), X1.20-1 (20), X1.20-2 (20)
unnamed: LED1_1_1.K (C), LED1_2_2.A
unnamed: LED1_2_2.K (C), LED1_3_3.A
unnamed: LED1_3_3.K (C), LED1_4_4.A
unnamed: LED1_1_12.A, LED1_4_10.K (C)
unnamed: LED1_2_8.K (C), LED1_3_9.A
unnamed: LED1_3_9.K (C), LED1_4_10.A
unnamed: LED1_1_17.A, LED1_4_15.K (C)
unnamed: LED1_1_12.K (C), LED1_2_13.A
unnamed: LED1_3_14.K (C), LED1_4_15.A
unnamed: LED2_2_11.K (C), LED2_3_12.A
unnamed: LED1_1_17.K (C), LED1_2_18.A
unnamed: LED1_2_18.K (C), LED1_3_19.A
unnamed: LED1_3_19.K (C), LED1_4_20.A
unnamed: LED2_1_2.K (C), LED2_2_3.A
unnamed: LED2_2_3.K (C), LED2_3_4.A
unnamed: LED2_3_4.K (C), LED2_4_5.A
unnamed: LED2_1_6.A, LED2_4_5.K (C)
unnamed: LED2_3_16.K (C), LED2_4_17.A
unnamed: LED2_2_7.K (C), LED2_3_8.A
unnamed: LED2_1_10.A, LED2_4_9.K (C)
unnamed: LED2_1_10.K (C), LED2_2_11.A
unnamed: LED3_1_3.K (C), LED3_2_4.A
unnamed: LED2_3_12.K (C), LED2_4_13.A
unnamed: LED2_1_14.A, LED2_4_13.K (C)
unnamed: LED2_1_14.K (C), LED2_2_15.A
unnamed: LED3_2_4.K (C), LED3_3_5.A
unnamed: LED2_1_19.A, LED2_4_17.K (C)
unnamed: LED2_1_19.K (C), LED2_2_20.A
unnamed: LED2_2_20.K (C), LED2_3_21.A
unnamed: LED2_3_21.K (C), LED2_4_1.A
unnamed: LED3_3_5.K (C), LED3_4_6.A
unnamed: LED3_1_4.A, LED3_4_6.K (C)
unnamed: LED3_1_4.K (C), LED3_2_5.A
unnamed: LED3_2_5.K (C), LED3_3_6.A
unnamed: LED3_3_6.K (C), LED3_4_7.A
unnamed: LED3_1_5.K (C), LED3_2_6.A
unnamed: LED3_2_6.K (C), LED3_3_7.A
unnamed: LED3_3_7.K (C), LED3_4_8.A
unnamed: LED3_1_8.A, LED3_4_8.K (C)
unnamed: LED3_1_8.K (C), LED3_2_9.A
unnamed: LED3_2_9.K (C), LED3_3_10.A
unnamed: LED3_3_10.K (C), LED3_4_11.A
unnamed: LED3_1_9.K (C), LED3_2_10.A
unnamed: LED3_2_10.K (C), LED3_3_11.A
unnamed: LED3_3_11.K (C), LED3_4_12.A
unnamed: LED3_1_11.A, LED3_4_12.K (C)
unnamed: LED3_1_11.K (C), LED3_2_12.A
unnamed: LED3_2_12.K (C), LED3_3_13.A
unnamed: LED3_3_13.K (C), LED3_4_14.A
unnamed: LED3_1_13.K (C), LED3_2_14.A
unnamed: LED3_2_14.K (C), LED3_3_15.A
unnamed: LED3_3_15.K (C), LED3_4_16.A
unnamed: LED3_1_15.A, LED3_4_16.K (C)
unnamed: LED3_1_15.K (C), LED3_2_16.A
unnamed: LED3_2_16.K (C), LED3_3_17.A
unnamed: LED3_3_17.K (C), LED3_4_18.A
unnamed: LED3_1_16.K (C), LED3_2_17.A
unnamed: LED3_2_17.K (C), LED3_3_18.A
unnamed: LED3_3_18.K (C), LED3_4_19.A
unnamed: LED3_1_18.A, LED3_4_19.K (C)
unnamed: LED3_1_18.K (C), LED3_2_19.A
unnamed: LED3_2_19.K (C), LED3_3_20.A
unnamed: LED3_3_20.K (C), LED3_4_21.A
unnamed: LED3_1_20.K (C), LED3_2_21.A
unnamed: LED3_2_21.K (C), LED3_3_1.A
unnamed: LED3_3_1.K (C), LED3_4_2.A
unnamed: LED3_1_21.A, LED3_4_2.K (C)
unnamed: LED3_1_21.K (C), LED3_2_1.A
unnamed: LED3_2_1.K (C), LED3_3_2.A
unnamed: LED3_3_2.K (C), LED3_4_3.A
unnamed: LED1_1_7.A, LED1_4_4.K (C)
unnamed: LED2_1_6.K (C), LED2_2_7.A

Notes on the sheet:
Copyright (c) 2020 - 2024 Bonn-Rhein-Sieg University of Applied Sciences Licensed under the terms of CC BY-SA

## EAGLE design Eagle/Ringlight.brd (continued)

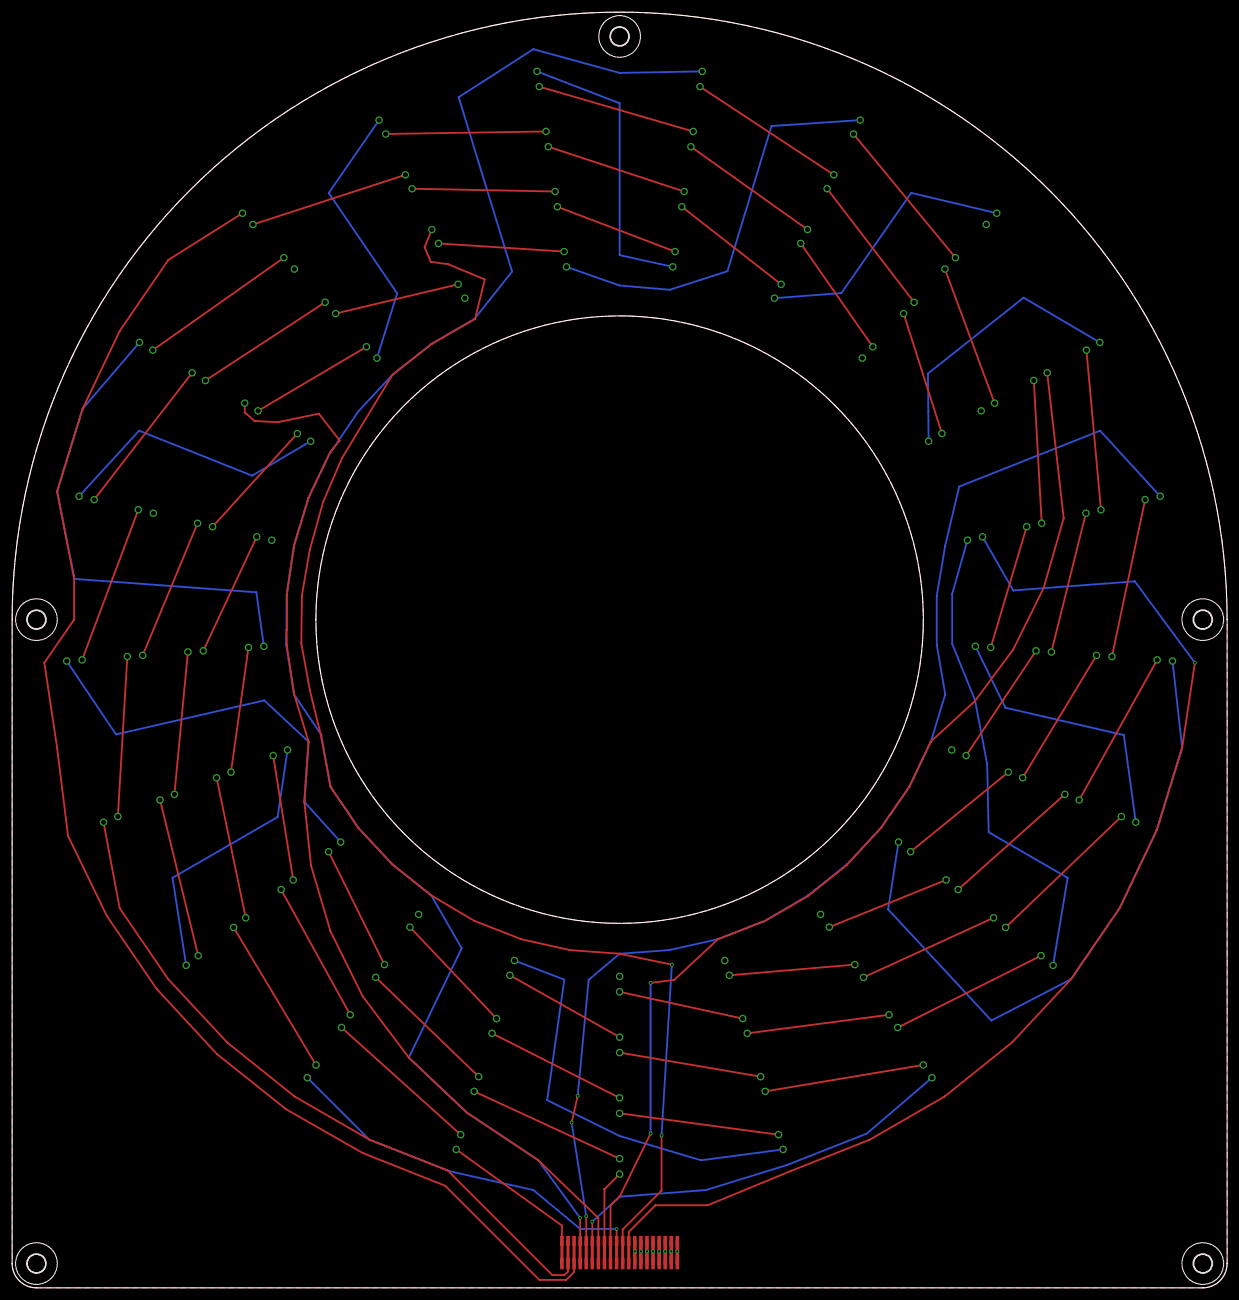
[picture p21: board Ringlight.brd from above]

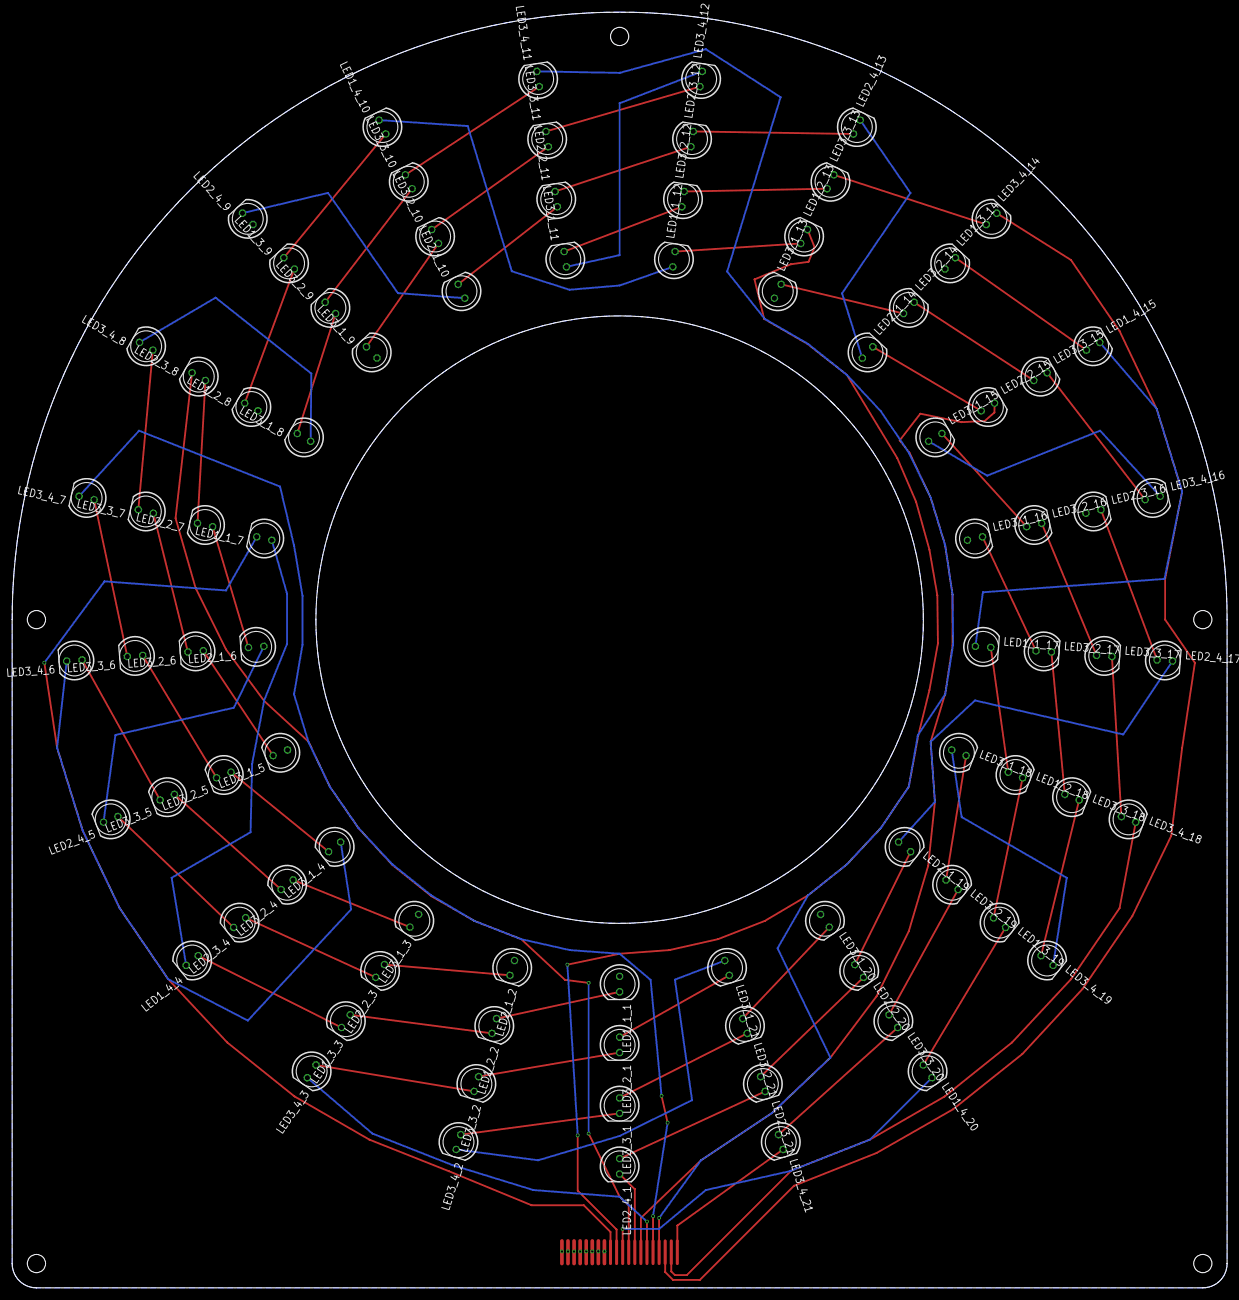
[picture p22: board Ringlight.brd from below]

Board: 2 copper layers, 200.0 x 210.0 mm, 90 parts (84 on the bottom side), 85 nets.

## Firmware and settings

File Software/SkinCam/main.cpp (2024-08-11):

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
#include "mainwindow.h"
#include "openclwrapper.h"
#include "skincamsystem.h"

#ifdef SKINCAM_ENABLE_VIMBA
#include "vimbaloader.h"
#endif

#include <QApplication>
#include <QCommandLineParser>
#include <QMessageBox>

// ---------------------------------------------------------------------------------------------- //

using namespace SkinCam;

// ---------------------------------------------------------------------------------------------- //

auto main(int argc, char* argv[]) -> int
{
    // Needed for queued connections
    qRegisterMetaType<Frame>("Frame");
    qRegisterMetaType<std::vector<Rect>>("std::vector<Rect>");

    QApplication::setOrganizationName("Bonn-Rhein-Sieg University of Applied Sciences");
    QApplication::setApplicationName("SkinCam Viewer");
    QApplication::setApplicationVersion(SKINCAM_VERSION);

    // Needed for toggling fullscreen mode without crashing
    QApplication::setAttribute(Qt::AA_ShareOpenGLContexts);

    QCommandLineParser parser;
    parser.setApplicationDescription("Frontend to the SkinCam camera system.");
    parser.addHelpOption();
    parser.addVersionOption();

    QCommandLineOption platformOption("platform-match",
                                      "Prefer OpenCL platforms whose names contain given string.",
                                      "filter");
    parser.addOption(platformOption);

    QCommandLineOption deviceOption("device-match",
                                    "Prefer OpenCL devices whose names contain given string.",
                                    "filter");
    parser.addOption(deviceOption);

    QCommandLineOption testmodeOption("testmode", "Enables some extra features for testing.");
    parser.addOption(testmodeOption);

    QApplication application(argc, argv);
    parser.process(application);

    Logger::info("SkinCam started.\n");

    try {
        const std::string platformFilter = parser.value(platformOption).toStdString();
        const std::string deviceFilter = parser.value(deviceOption).toStdString();

        OpenCLWrapper opencl(platformFilter, deviceFilter);

#ifdef SKINCAM_ENABLE_VIMBA
        VimbaLoader vimba;
#endif

        SkinCamSystem skinCam;

        MainWindow window(&skinCam, parser.isSet(testmodeOption));
        window.show();

        return QApplication::exec();
    }
    catch (const std::exception& e)
    {
        QMessageBox::critical(nullptr, "Error", e.what());
        return -1;
    }
}

// ---------------------------------------------------------------------------------------------- //

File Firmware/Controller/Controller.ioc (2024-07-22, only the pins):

Mcu.UserName=STM32L412KBTx
PA0-CK_IN.GPIO_Label=DIM1
PA0-CK_IN.Signal=S_TIM2_CH1
PA1.GPIO_Label=DIM2
PA1.Signal=S_TIM2_CH2
PA11.Signal=USB_DM
PA12.Signal=USB_DP
PA2.GPIO_Label=DIM3
PA2.Signal=S_TIM2_CH3
PA3.GPIO_Label=DIM4
PA3.Signal=S_TIM2_CH4
PA6.GPIO_Label=TRIGGER_TTL
PA6.Signal=GPIO_Output
PA7.GPIO_Label=TRIGGER_ISO
PA7.Signal=GPIO_Output
PB0.GPIO_Label=FEEDBACK_TTL
PB0.Signal=GPIO_Input
PB1.GPIO_Label=FEEDBACK_ISO
PB1.Signal=GPIO_Input
PB5.GPIO_Label=STATUS_BAD
PB5.Signal=GPIO_Output
PB6.GPIO_Label=SCL
PB6.Signal=I2C1_SCL
PB7.GPIO_Label=SDA
PB7.Signal=I2C1_SDA

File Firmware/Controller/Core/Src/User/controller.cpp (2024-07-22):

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
#include "assert.h"
#include "controller.h"
#include "delay.h"

#include <algorithm>
#include <numeric>

// ---------------------------------------------------------------------------------------------- //

namespace {
    constexpr auto PowerMonitorHandle = Config::PowerMonitorHandle;
    constexpr auto PowerMonitorAddress = Config::PowerMonitorAddress;
    constexpr auto PowerMonitorResistance = Config::PowerMonitorResistance;

    volatile bool g_monitorPeriodElapsed = false;

    volatile bool g_activityTimerActive = false;
    volatile bool g_activityFlag = false;
}

// ---------------------------------------------------------------------------------------------- //

namespace ControlRequest
{
    constexpr uint8_t GetStatus = 0x01;
    constexpr uint8_t GetError = 0x02;

    constexpr uint8_t SetSequenceConfiguration = 0x03;
    constexpr uint8_t GetSequenceConfiguration = 0x04;

    constexpr uint8_t SetPowerConfiguration = 0x05;
    constexpr uint8_t GetPowerConfiguration = 0x06;

    constexpr uint8_t GetPowerStatus = 0x07;

    constexpr uint8_t RunSequence = 0x08;
    constexpr uint8_t WaitSequenceComplete = 0x09;

    constexpr uint8_t ClearErrors = 0x10;
}

// ---------------------------------------------------------------------------------------------- //

void HAL_TIM_PeriodElapsedCallback(TIM_HandleTypeDef* htim)
{
    ASSERT(htim == Config::MonitorTimerHandle || htim == Config::ActivityTimerHandle);

    if (htim == Config::MonitorTimerHandle)
        g_monitorPeriodElapsed = true;
    else if (htim == Config::ActivityTimerHandle)
    {
        if (g_activityFlag)
        {
            HAL_GPIO_TogglePin(STATUS_GOOD_GPIO_Port, STATUS_GOOD_Pin);
            g_activityFlag = false;
        }
        else
        {
            HAL_GPIO_WritePin(STATUS_GOOD_GPIO_Port, STATUS_GOOD_Pin, GPIO_PIN_RESET);
            HAL_TIM_Base_Stop_IT(htim);
            g_activityTimerActive = false;
        }
    }
}

// ---------------------------------------------------------------------------------------------- //

template <typename T>
auto inRange(T x, T min, T max) -> bool
{
    return x >= min && x <= max;
}

// ---------------------------------------------------------------------------------------------- //

Controller::Controller()
    : m_hostInterface(this),
      m_powerMonitor(PowerMonitorHandle, PowerMonitorAddress, PowerMonitorResistance)
{
}

// ---------------------------------------------------------------------------------------------- //

void Controller::exec()
{
    HAL_GPIO_WritePin(LED_ENABLE_GPIO_Port, LED_ENABLE_Pin, GPIO_PIN_SET);

    // Wait for LED power to become stable and
    // power monitor to complete first sample
    Delay::wait(500ms);

    HAL_TIM_Base_Start_IT(Config::MonitorTimerHandle);

    HAL_GPIO_WritePin(STATUS_GOOD_GPIO_Port, STATUS_GOOD_Pin, GPIO_PIN_RESET);

    while (true)
    {
        switch (m_currentTask)
        {
        case Task::ApplySequenceConfiguration:
            processApplySequenceConfiguration();
            break;

        case Task::ApplyPowerConfiguration:
            processApplyPowerConfiguration();
            break;

        case Task::RunSequence:
            processRunSequence();
            break;

        case Task::WaitSequenceComplete:
            processWaitSequenceComplete();
            break;

        case Task::ClearErrors:
            processClearErrors();
            break;

        default:
            break;
        }

        if (g_monitorPeriodElapsed)
        {
            g_monitorPeriodElapsed = false;
            updatePowerStatus();
        }
    }
}

// ---------------------------------------------------------------------------------------------- //

void Controller::onInitComplete()
{
    m_status = Status::Ready;
}

// ---------------------------------------------------------------------------------------------- //

void Controller::onControlOutReceived(uint8_t request, const uint8_t* data, uint16_t length)
{
    if (m_status == Status::Busy)
        return;

    m_status = Status::Busy;
    m_error = Error::NoError;

    if (request == ControlRequest::SetSequenceConfiguration)
    {
        if (length == sizeof(SequenceConfiguration))
        {
            const auto& config = *reinterpret_cast<const SequenceConfiguration*>(data);

            if (configurationValid(config))
            {
                m_sequenceConfiguration = config;
                m_currentTask = Task::ApplySequenceConfiguration;
            }
            else
                m_error = Error::InvalidParameter;
        }
        else
            m_error = Error::InvalidLength;
    }
    else if (request == ControlRequest::SetPowerConfiguration)
    {
        if (length == sizeof(PowerConfiguration))
        {
            const auto& config = *reinterpret_cast<const PowerConfiguration*>(data);

            if (configurationValid(config))
            {
                m_powerConfiguration = config;
                m_currentTask = Task::ApplyPowerConfiguration;
            }
            else
                m_error = Error::InvalidParameter;
        }
        else
            m_error = Error::InvalidLength;
    }
    else if (request == ControlRequest::RunSequence)
    {
        if (length == 0)
            m_currentTask = Task::RunSequence;
        else
            m_error = Error::InvalidLength;
    }
    else if (request == ControlRequest::WaitSequenceComplete)
    {
        if (length == 0)
            m_currentTask = Task::WaitSequenceComplete;
        else
            m_error = Error::InvalidLength;
    }
    else if (request == ControlRequest::ClearErrors)
    {
        if (length == 0)
            m_currentTask = Task::ClearErrors;
        else
            m_error = Error::InvalidLength;
    }
    else
        m_error = Error::InvalidCommand;

    if (m_error != Error::NoError)
        m_status = Status::Error;
}

// ---------------------------------------------------------------------------------------------- //
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

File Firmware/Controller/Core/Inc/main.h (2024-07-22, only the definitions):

#define LED_ENABLE_Pin GPIO_PIN_14
#define LED_ENABLE_GPIO_Port GPIOC
#define DIM1_Pin GPIO_PIN_0
#define DIM1_GPIO_Port GPIOA
#define DIM2_Pin GPIO_PIN_1
#define DIM2_GPIO_Port GPIOA
#define DIM3_Pin GPIO_PIN_2
#define DIM3_GPIO_Port GPIOA
#define DIM4_Pin GPIO_PIN_3
#define DIM4_GPIO_Port GPIOA
#define TRIGGER_TTL_Pin GPIO_PIN_6
#define TRIGGER_TTL_GPIO_Port GPIOA
#define TRIGGER_ISO_Pin GPIO_PIN_7
#define TRIGGER_ISO_GPIO_Port GPIOA
#define FEEDBACK_TTL_Pin GPIO_PIN_0
#define FEEDBACK_TTL_GPIO_Port GPIOB
#define FEEDBACK_ISO_Pin GPIO_PIN_1
#define FEEDBACK_ISO_GPIO_Port GPIOB
#define DEBUG_PIN_Pin GPIO_PIN_15
#define DEBUG_PIN_GPIO_Port GPIOA
#define STATUS_GOOD_Pin GPIO_PIN_4
#define STATUS_GOOD_GPIO_Port GPIOB
#define STATUS_BAD_Pin GPIO_PIN_5
#define STATUS_BAD_GPIO_Port GPIOB
#define SCL_Pin GPIO_PIN_6
#define SCL_GPIO_Port GPIOB
#define SDA_Pin GPIO_PIN_7
#define SDA_GPIO_Port GPIOB

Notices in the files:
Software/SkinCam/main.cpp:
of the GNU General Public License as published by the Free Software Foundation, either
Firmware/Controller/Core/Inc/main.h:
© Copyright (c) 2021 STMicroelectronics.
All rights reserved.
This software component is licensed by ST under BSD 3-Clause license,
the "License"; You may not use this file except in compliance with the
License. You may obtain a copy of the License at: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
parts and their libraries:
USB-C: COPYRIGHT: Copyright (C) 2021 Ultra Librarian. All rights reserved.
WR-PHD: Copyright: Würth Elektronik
